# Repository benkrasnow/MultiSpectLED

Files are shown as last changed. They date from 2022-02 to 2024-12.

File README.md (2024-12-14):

# MultiSpectLED
Array of 15 1W LEDs spanning 280nm to 940nm


Notes:  The 280nm LED has a forward voltage drop of between 5V and 7.5V depending on the voltage bin.  This is higher that I expected when I designed the circuit, and it will not work if the power supply is really 5.0V.  It should have a boost converter instead of a buck converter.  However, I happened to receive an LED with a 5.1V drop, and my 5V wall adapter supplies 5.35V at 500mA, so the system works with the buck converter, just barely.  This part of the circuit should be redesigned if 280nm is needed.

UPDATE:  I added 0402 resistors near each buck controller.
The "enable" pin on the PAM2804 buck controller is very high-impedance, and will float around while the MCU is being programmed.  This causes bright flashes, and potentially can draw too much current from the supply, so pull-down resistors *MUST* be added between each PWM control line and ground.  I haven't updated the PCB yet, and fixed it in the prototype by adding resistors:

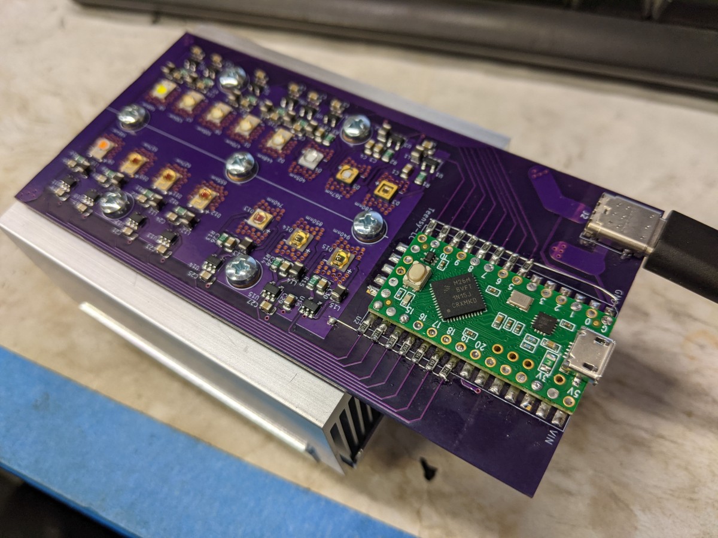
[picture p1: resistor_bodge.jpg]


The heatsink has a 45mm wide rasied section, and the PCB is designed so that all exposed copper is ground within this 45mm strip. I used the PCB itself as a drill guide to drill 2.5mm holes, and then tapped them M3.  I used M3x4 screws to hold the PCB to the heatsink.

Originally, I planned to use Luxeon IR LEDs from Lumileds for the 850 and 940nm.  The thermal pad on these is tied to the anode, so it will not work with the current PCB design. I replaced them with alternate parts with very similar footprint, and have updated the BOM and layout.  

Heatsink and fan: https://www.amazon.com/dp/B00006B8EX
The fan runs nice and quiet on 5V, and provides more than enough airflow

USB-C 5V 4A power adapter:  Digikey 1597-106060004-ND  This should have enough current capacity to run up to 8 LEDs at full power.

Each LED channel is configured for 500mA , which is set by the 0.2 ohm resistor and internal 0.1V reference of the buck controller IC, PAM2804.
Dimming is achieved with PWM, and I used "software PWM" to get 15 separate channels from the Teensy-LC.  The SoftPWM library defaults to 60Hz update, which I noticed flickering, so I edited SoftPWM.cpp to use 120Hz instead.  MCUs with 15+ hardware PWM channels exist, but are more expensive, and not easy to find these days!

The Teensy-LC also provides easy programability for external triggering, remote control via USB serial, etc

The +5V power connection on the Teensy-LC between its USB micro plug and Vin pin should be cut.  There is a thin link between two exposed pads on the underside for this purpose.  This allows the Teensy to be powered only by the Vin pin, which is connected to the USB-C power rail in this design (it must be powered for programming).  If the link is not cut, and both USB connections are made with mismatched voltages (eg 4.9V vs 5.3V), bad currents may flow.

Total cost is about $180, and the 280nm LED alone is $24

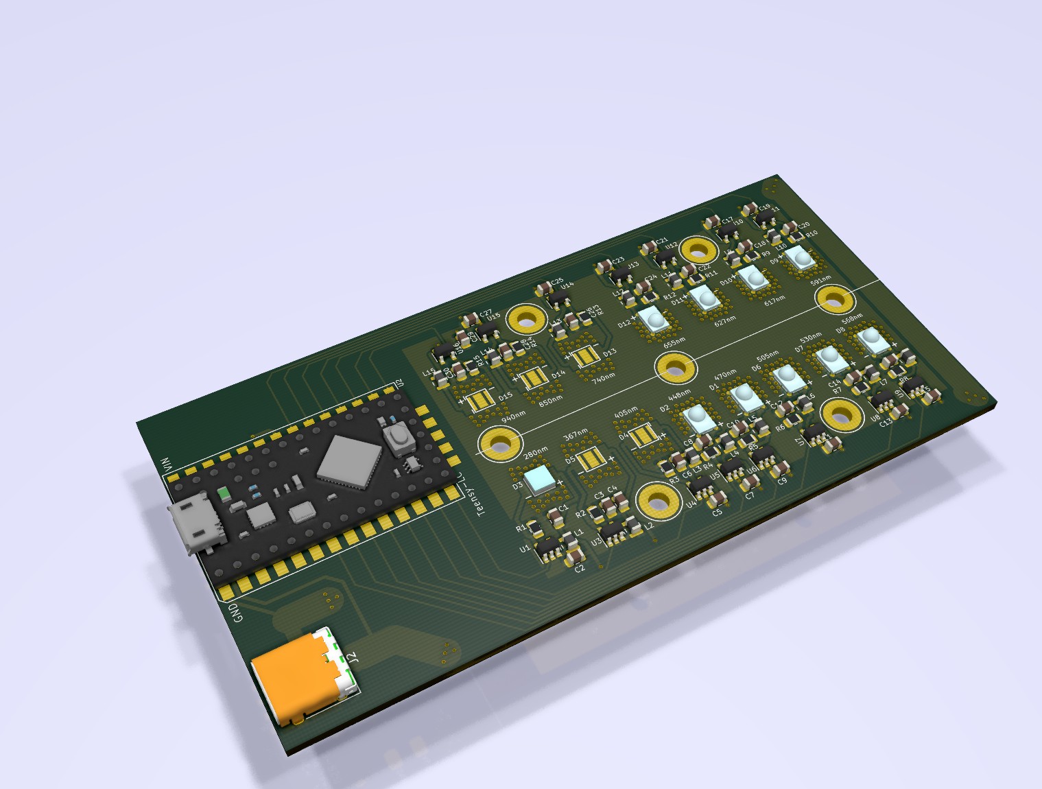
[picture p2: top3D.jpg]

.

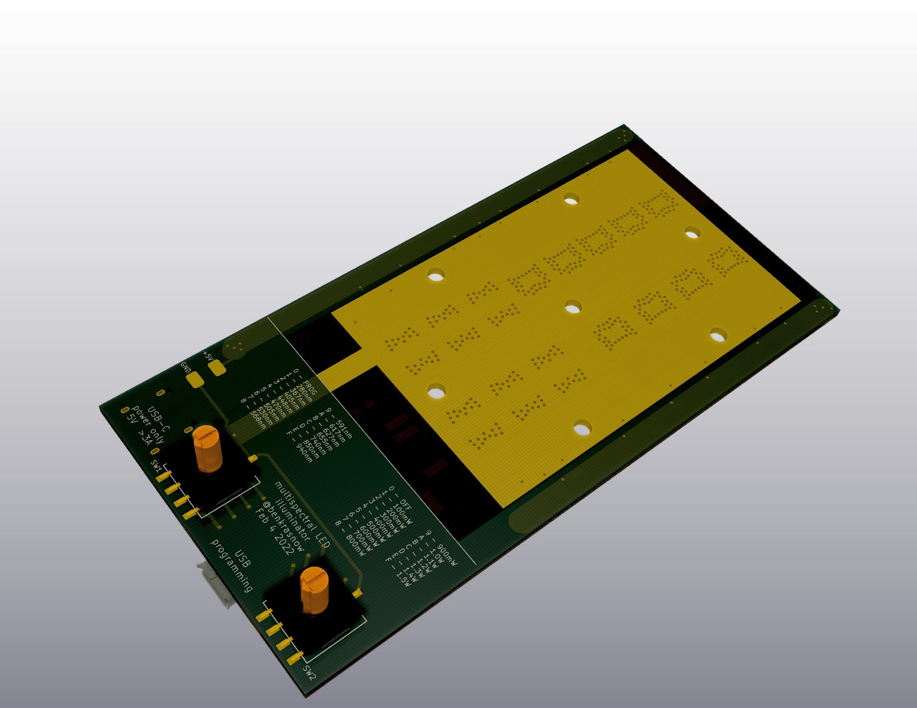
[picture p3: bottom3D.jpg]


Thermal performance looks very good.  At 16C ambient, the hottest part is the inductor at 23C.
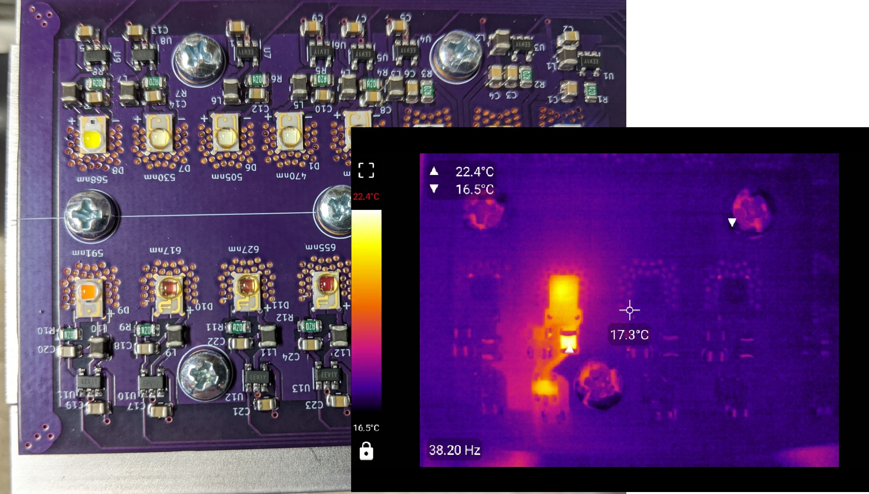
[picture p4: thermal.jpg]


Device was used to create Silver nanoprisms grown into structural colors by high power LEDs

A video can be found here - https://www.youtube.com/watch?v=v8pko9IlFW4

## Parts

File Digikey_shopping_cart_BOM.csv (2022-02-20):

Index | Quantity | Part Number | Manufacturer Part Number | Description | Customer Reference | Available | Backorder | Unit Price | Extended Price USD
1 | 1 | 1416-1038-1-ND | LXML-PR01-0500 | LED LUXEON REBEL BLUE 448NM SMD |  | 1 | 0 | 3.19000 | 3.19
2 | 1 | 1416-1029-1-ND | LXML-PB01-0040 | LED LUXEON REBEL BLUE 470NM SMD |  | 1 | 0 | 4.20000 | 4.20
3 | 1 | 1416-1031-1-ND | LXML-PE01-0070 | LED LUXEON REBEL CYAN 505NM SMD |  | 1 | 0 | 4.47000 | 4.47
4 | 1 | 1416-1036-1-ND | LXML-PM01-0100 | LED LUXEON REBEL GREEN 530NM SMD |  | 1 | 0 | 4.49000 | 4.49
5 | 1 | 1416-1185-1-ND | LXML-PX02-0000 | LED LUXEON REBEL LIME 568NM SMD |  | 1 | 0 | 5.04000 | 5.04
6 | 1 | 1416-1027-1-ND | LXM2-PL01-0000 | LED LUXEON REBEL AMBER 591NM SMD |  | 1 | 0 | 4.49000 | 4.49
7 | 1 | 1416-1026-1-ND | LXM2-PH01-0070 | LED LUXEON REBEL ORG 617NM SMD |  | 1 | 0 | 3.52000 | 3.52
8 | 1 | 1416-1024-1-ND | LXM2-PD01-0050 | LED LUXEON REBEL RED 627NM SMD |  | 1 | 0 | 3.36000 | 3.36
9 | 1 | 1416-1701-1-ND | LXM3-PD01 | LED LUXEON REBEL RED 655NM SMD |  | 1 | 0 | 3.07000 | 3.07
10 | 1 | 1214-XBT-3535-UV-A130-CD270-00CT-ND | XBT-3535-UV-A130-CD270-00 | EMITTER UV 270NM MODULE |  | 1 | 0 | 23.77000 | 23.77
11 | 1 | 2112-CUN6GF1ACT-ND | CUN6GF1A | 367NM CA3535_FLAT PACKAGE |  | 1 | 0 | 9.40000 | 9.40
12 | 1 | 1080-1620-1-ND | ELUA3535OGB-P0010U23240500-VD1M | EMITTER UV 405NM 1000MA SMD |  | 1 | 0 | 3.43000 | 3.43
13 | 1 | 1516-1213-1-ND | QBHP684-IR4BU | LED IR 740NM 700MA SMD |  | 1 | 0 | 5.51000 | 5.51
14 | 25 | PAM2804AAB010DICT-ND | PAM2804AAB010 | IC LED DRIVER RGLTR 1A TSOT25 |  | 25 | 0 | 0.55440 | 13.86
15 | 25 | 587-1621-1-ND | CBC2518T4R7M | FIXED IND 4.7UH 920MA 260MOHM SM |  | 25 | 0 | 0.17600 | 4.40
16 | 50 | 490-3886-1-ND | GRM21BR61C106KE15L | CAP CER 10UF 16V X5R 0805 |  | 50 | 0 | 0.07420 | 3.71
17 | 25 | RL12S.20FCT-ND | RL1220S-R20-F | RES 0.2 OHM 1% 1/3W 0805 |  | 25 | 0 | 0.17640 | 4.41
18 | 1 | 237-1419-ND | WSU050-4000 | AC/DC WALL MOUNT ADAPTER 5V 20W |  | 1 | 0 | 16.01000 | 16.01
19 | 1 | 1568-1233-ND | DEV-13305 | TEENSY-LC KL2X EVAL BRD |  | 1 | 0 | 14.38000 | 14.38
20 | 2 | 360-2543-1-ND | FR02KR16P-R | SWITCH ROTARY DIP HEX 100MA 5V |  | 2 | 0 | 3.76000 | 7.52
21 | 1 | 1516-1173-1-ND | QBHP684U-IRU | EMITTER IR 850NM 700MA SMD |  | 1 | 0 | 4.66000 | 4.66
22 | 1 | 1516-1210-1-ND | QBHP684-IR1BU | LED IR 940NM 700MA SMD |  | 1 | 0 | 4.47000 | 4.47

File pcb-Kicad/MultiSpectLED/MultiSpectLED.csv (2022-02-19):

Source: | C:\Users\Ben\Desktop\MultiSpectLED\MultiSpectLED.sch
Date: | 02/19/22 12:57:11
Tool: | Eeschema (5.1.4)-1
Generator: | C:\Program Files\KiCad\bin\scripting\plugins/bom_csv_grouped_by_value.py
Component Count: | 102
Individual Components:
Item | Qty | Reference(s) | Value | LibPart | Footprint | Datasheet | Digikey Part Number
 |  | C1 | C | MultiSpectLED:C | MultiSpectLED:C_0805_2012Metric | ~ | 490-3886-1-ND
 |  | C2 | C | MultiSpectLED:C | MultiSpectLED:C_0805_2012Metric | ~ | 490-3886-1-ND
 |  | C3 | C | MultiSpectLED:C | MultiSpectLED:C_0805_2012Metric | ~ | 490-3886-1-ND
 |  | C4 | C | MultiSpectLED:C | MultiSpectLED:C_0805_2012Metric | ~ | 490-3886-1-ND
 |  | C5 | C | MultiSpectLED:C | MultiSpectLED:C_0805_2012Metric | ~ | 490-3886-1-ND
 |  | C6 | C | MultiSpectLED:C | MultiSpectLED:C_0805_2012Metric | ~ | 490-3886-1-ND
 |  | C7 | C | MultiSpectLED:C | MultiSpectLED:C_0805_2012Metric | ~ | 490-3886-1-ND
 |  | C8 | C | MultiSpectLED:C | MultiSpectLED:C_0805_2012Metric | ~ | 490-3886-1-ND
 |  | C9 | C | MultiSpectLED:C | MultiSpectLED:C_0805_2012Metric | ~ | 490-3886-1-ND
 |  | C10 | C | MultiSpectLED:C | MultiSpectLED:C_0805_2012Metric | ~ | 490-3886-1-ND
 |  | C11 | C | MultiSpectLED:C | MultiSpectLED:C_0805_2012Metric | ~ | 490-3886-1-ND
 |  | C12 | C | MultiSpectLED:C | MultiSpectLED:C_0805_2012Metric | ~ | 490-3886-1-ND
 |  | C13 | C | MultiSpectLED:C | MultiSpectLED:C_0805_2012Metric | ~ | 490-3886-1-ND
 |  | C14 | C | MultiSpectLED:C | MultiSpectLED:C_0805_2012Metric | ~ | 490-3886-1-ND
 |  | C15 | C | MultiSpectLED:C | MultiSpectLED:C_0805_2012Metric | ~ | 490-3886-1-ND
 |  | C16 | C | MultiSpectLED:C | MultiSpectLED:C_0805_2012Metric | ~ | 490-3886-1-ND
 |  | C17 | C | MultiSpectLED:C | MultiSpectLED:C_0805_2012Metric | ~ | 490-3886-1-ND
 |  | C18 | C | MultiSpectLED:C | MultiSpectLED:C_0805_2012Metric | ~ | 490-3886-1-ND
 |  | C19 | C | MultiSpectLED:C | MultiSpectLED:C_0805_2012Metric | ~ | 490-3886-1-ND
 |  | C20 | C | MultiSpectLED:C | MultiSpectLED:C_0805_2012Metric | ~ | 490-3886-1-ND
 |  | C21 | C | MultiSpectLED:C | MultiSpectLED:C_0805_2012Metric | ~ | 490-3886-1-ND
 |  | C22 | C | MultiSpectLED:C | MultiSpectLED:C_0805_2012Metric | ~ | 490-3886-1-ND
 |  | C23 | C | MultiSpectLED:C | MultiSpectLED:C_0805_2012Metric | ~ | 490-3886-1-ND
 |  | C24 | C | MultiSpectLED:C | MultiSpectLED:C_0805_2012Metric | ~ | 490-3886-1-ND
 |  | C25 | C | MultiSpectLED:C | MultiSpectLED:C_0805_2012Metric | ~ | 490-3886-1-ND
 |  | C26 | C | MultiSpectLED:C | MultiSpectLED:C_0805_2012Metric | ~ | 490-3886-1-ND
 |  | C27 | C | MultiSpectLED:C | MultiSpectLED:C_0805_2012Metric | ~ | 490-3886-1-ND
 |  | C28 | C | MultiSpectLED:C | MultiSpectLED:C_0805_2012Metric | ~ | 490-3886-1-ND
 |  | C29 | C | MultiSpectLED:C | MultiSpectLED:C_0805_2012Metric | ~ | 490-3886-1-ND
 |  | C30 | C | MultiSpectLED:C | MultiSpectLED:C_0805_2012Metric | ~ | 490-3886-1-ND
 |  | D1 | 470nm | MultiSpectLED:LED_PAD | MultiSpectLED:LuxeonRebelColor | ~ | 1416-1029-1-ND
 |  | D2 | 448nm | MultiSpectLED:LED_PAD | MultiSpectLED:LuxeonRebelColor | ~ | 1416-1038-1-ND
 |  | D3 | 280nm | MultiSpectLED:LED_PAD | MultiSpectLED:Luminus_XBT3535 | ~ | 1214-XBT-3535-UV-A130-CD270-00CT-ND
 |  | D4 | 405nm | MultiSpectLED:LED_PAD_ANODE_MARKED | MultiSpectLED:Everlight_ELUA3535 | ~ | 1080-1620-1-ND
 |  | D5 | 367nm | MultiSpectLED:LED_PAD | MultiSpectLED:SeoulViosys_CUN6GF1A | ~ | 2112-CUN6GF1ACT-ND
 |  | D6 | 505nm | MultiSpectLED:LED_PAD | MultiSpectLED:LuxeonRebelColor | ~ | 1416-1031-1-ND
 |  | D7 | 530nm | MultiSpectLED:LED_PAD | MultiSpectLED:LuxeonRebelColor | ~ | 1416-1036-1-ND
 |  | D8 | 568nm | MultiSpectLED:LED_PAD | MultiSpectLED:LuxeonRebelColor | ~ | 1416-1185-1-ND
 |  | D9 | 591nm | MultiSpectLED:LED_PAD | MultiSpectLED:LuxeonRebelColor | ~ | 1416-1027-1-ND
 |  | D10 | 617nm | MultiSpectLED:LED_PAD | MultiSpectLED:LuxeonRebelColor | ~ | 1416-1026-1-ND
 |  | D11 | 627nm | MultiSpectLED:LED_PAD | MultiSpectLED:LuxeonRebelColor | ~ | 1416-1024-1-ND
 |  | D12 | 655nm | MultiSpectLED:LED_PAD | MultiSpectLED:LuxeonRebelColor | ~ | 1416-1701-1-ND
 |  | D13 | 740nm | MultiSpectLED:LED_PAD_ANODE_MARKED | MultiSpectLED:QT_Brightek_QBHP684 | ~ | 1516-1213-1-ND
 |  | D14 | 850nm | MultiSpectLED:LED_PAD_ANODE_MARKED | MultiSpectLED:QT_Brightek_QBHP684 | ~
 |  | D15 | 940nm | MultiSpectLED:LED_PAD_ANODE_MARKED | MultiSpectLED:QT_Brightek_QBHP684 | ~
 |  | H1 | 3mm_PTH | MultiSpectLED:3mm_PTH | MultiSpectLED:3mm_PTH
 |  | H2 | 3mm_PTH | MultiSpectLED:3mm_PTH | MultiSpectLED:3mm_PTH
 |  | H3 | 3mm_PTH | MultiSpectLED:3mm_PTH | MultiSpectLED:3mm_PTH
 |  | H4 | 3mm_PTH | MultiSpectLED:3mm_PTH | MultiSpectLED:3mm_PTH
 |  | H5 | 3mm_PTH | MultiSpectLED:3mm_PTH | MultiSpectLED:3mm_PTH
 |  | H6 | 3mm_PTH | MultiSpectLED:3mm_PTH | MultiSpectLED:3mm_PTH
 |  | H7 | 3mm_PTH | MultiSpectLED:3mm_PTH | MultiSpectLED:3mm_PTH
 |  | J1 | Conn_01x02_Female | Connector:Conn_01x02_Female | MultiSpectLED:FAN_PADS | ~
 |  | J2 | USB_C_Receptacle_USB2.0 | Connector:USB_C_Receptacle_USB2.0 | MultiSpectLED:USB_C_Receptacle_Amphenol_12401610E4-2A | https://www.usb.org/sites/default/files/documents/usb_type-c.zip | CP-036AHPJCT-ND
 |  | L1 | 4.7u | MultiSpectLED:L | MultiSpectLED:L_1007_2518Metric | ~ | 587-1621-1-ND
 |  | L2 | 4.7u | MultiSpectLED:L | MultiSpectLED:L_1007_2518Metric | ~ | 587-1621-1-ND
 |  | L3 | 4.7u | MultiSpectLED:L | MultiSpectLED:L_1007_2518Metric | ~ | 587-1621-1-ND
 |  | L4 | 4.7u | MultiSpectLED:L | MultiSpectLED:L_1007_2518Metric | ~ | 587-1621-1-ND
 |  | L5 | 4.7u | MultiSpectLED:L | MultiSpectLED:L_1007_2518Metric | ~ | 587-1621-1-ND
 |  | L6 | 4.7u | MultiSpectLED:L | MultiSpectLED:L_1007_2518Metric | ~ | 587-1621-1-ND
 |  | L7 | 4.7u | MultiSpectLED:L | MultiSpectLED:L_1007_2518Metric | ~ | 587-1621-1-ND
 |  | L8 | 4.7u | MultiSpectLED:L | MultiSpectLED:L_1007_2518Metric | ~ | 587-1621-1-ND
 |  | L9 | 4.7u | MultiSpectLED:L | MultiSpectLED:L_1007_2518Metric | ~ | 587-1621-1-ND
 |  | L10 | 4.7u | MultiSpectLED:L | MultiSpectLED:L_1007_2518Metric | ~ | 587-1621-1-ND
 |  | L11 | 4.7u | MultiSpectLED:L | MultiSpectLED:L_1007_2518Metric | ~ | 587-1621-1-ND
 |  | L12 | 4.7u | MultiSpectLED:L | MultiSpectLED:L_1007_2518Metric | ~ | 587-1621-1-ND
 |  | L13 | 4.7u | MultiSpectLED:L | MultiSpectLED:L_1007_2518Metric | ~ | 587-1621-1-ND
 |  | L14 | 4.7u | MultiSpectLED:L | MultiSpectLED:L_1007_2518Metric | ~ | 587-1621-1-ND
 |  | L15 | 4.7u | MultiSpectLED:L | MultiSpectLED:L_1007_2518Metric | ~ | 587-1621-1-ND
 |  | R1 | 0.2 | MultiSpectLED:R | MultiSpectLED:R_0805_2012Metric | ~ | RL12S.20FCT-ND
 |  | R2 | 0.2 | MultiSpectLED:R | MultiSpectLED:R_0805_2012Metric | ~ | RL12S.20FCT-ND
 |  | R3 | 0.2 | MultiSpectLED:R | MultiSpectLED:R_0805_2012Metric | ~ | RL12S.20FCT-ND
 |  | R4 | 0.2 | MultiSpectLED:R | MultiSpectLED:R_0805_2012Metric | ~ | RL12S.20FCT-ND
 |  | R5 | 0.2 | MultiSpectLED:R | MultiSpectLED:R_0805_2012Metric | ~ | RL12S.20FCT-ND
 |  | R6 | 0.2 | MultiSpectLED:R | MultiSpectLED:R_0805_2012Metric | ~ | RL12S.20FCT-ND
 |  | R7 | 0.2 | MultiSpectLED:R | MultiSpectLED:R_0805_2012Metric | ~ | RL12S.20FCT-ND
 |  | R8 | 0.2 | MultiSpectLED:R | MultiSpectLED:R_0805_2012Metric | ~ | RL12S.20FCT-ND
 |  | R9 | 0.2 | MultiSpectLED:R | MultiSpectLED:R_0805_2012Metric | ~ | RL12S.20FCT-ND
 |  | R10 | 0.2 | MultiSpectLED:R | MultiSpectLED:R_0805_2012Metric | ~ | RL12S.20FCT-ND
 |  | R11 | 0.2 | MultiSpectLED:R | MultiSpectLED:R_0805_2012Metric | ~ | RL12S.20FCT-ND
 |  | R12 | 0.2 | MultiSpectLED:R | MultiSpectLED:R_0805_2012Metric | ~ | RL12S.20FCT-ND
 |  | R13 | 0.2 | MultiSpectLED:R | MultiSpectLED:R_0805_2012Metric | ~ | RL12S.20FCT-ND
 |  | R14 | 0.2 | MultiSpectLED:R | MultiSpectLED:R_0805_2012Metric | ~ | RL12S.20FCT-ND
 |  | R15 | 0.2 | MultiSpectLED:R | MultiSpectLED:R_0805_2012Metric | ~ | RL12S.20FCT-ND
 |  | SW1 | NKK_HEXADEC | MultiSpectLED:NKK_HEXADEC | MultiSpectLED:NKK_FR02 |  | 360-2543-1-ND
 |  | SW2 | NKK_HEXADEC | MultiSpectLED:NKK_HEXADEC | MultiSpectLED:NKK_FR02 |  | 360-2543-1-ND
 |  | U1 | PAM2804 | MultiSpectLED:PAM2804 | MultiSpectLED:SOT-23-5 |  | PAM2804AAB010DICT-ND
 |  | U2 | TeensyLC | MultiSpectLED:TeensyLC | MultiSpectLED:TeensyLC |  | 1568-1233-ND
 |  | U3 | PAM2804 | MultiSpectLED:PAM2804 | MultiSpectLED:SOT-23-5 |  | PAM2804AAB010DICT-ND
 |  | U4 | PAM2804 | MultiSpectLED:PAM2804 | MultiSpectLED:SOT-23-5 |  | PAM2804AAB010DICT-ND
 |  | U5 | PAM2804 | MultiSpectLED:PAM2804 | MultiSpectLED:SOT-23-5 |  | PAM2804AAB010DICT-ND
 |  | U6 | PAM2804 | MultiSpectLED:PAM2804 | MultiSpectLED:SOT-23-5 |  | PAM2804AAB010DICT-ND
 |  | U7 | PAM2804 | MultiSpectLED:PAM2804 | MultiSpectLED:SOT-23-5 |  | PAM2804AAB010DICT-ND
 |  | U8 | PAM2804 | MultiSpectLED:PAM2804 | MultiSpectLED:SOT-23-5 |  | PAM2804AAB010DICT-ND
 |  | U9 | PAM2804 | MultiSpectLED:PAM2804 | MultiSpectLED:SOT-23-5 |  | PAM2804AAB010DICT-ND
 |  | U10 | PAM2804 | MultiSpectLED:PAM2804 | MultiSpectLED:SOT-23-5 |  | PAM2804AAB010DICT-ND
 |  | U11 | PAM2804 | MultiSpectLED:PAM2804 | MultiSpectLED:SOT-23-5 |  | PAM2804AAB010DICT-ND
 |  | U12 | PAM2804 | MultiSpectLED:PAM2804 | MultiSpectLED:SOT-23-5 |  | PAM2804AAB010DICT-ND
 |  | U13 | PAM2804 | MultiSpectLED:PAM2804 | MultiSpectLED:SOT-23-5 |  | PAM2804AAB010DICT-ND
 |  | U14 | PAM2804 | MultiSpectLED:PAM2804 | MultiSpectLED:SOT-23-5 |  | PAM2804AAB010DICT-ND
 |  | U15 | PAM2804 | MultiSpectLED:PAM2804 | MultiSpectLED:SOT-23-5 |  | PAM2804AAB010DICT-ND
 |  | U16 | PAM2804 | MultiSpectLED:PAM2804 | MultiSpectLED:SOT-23-5 |  | PAM2804AAB010DICT-ND
Collated Components:
Item | Qty | Reference(s) | Value | LibPart | Footprint | Datasheet | Digikey Part Number
1 | 30 | C1, C2, C3, C4, C5, C6, C7, C8, C9, C10, C11, C12, C13, C14, C15, C16, C17, C18, C19, C20, C21, C22, C23, C24, C25, C26, C27, C28, C29, C30 | C | MultiSpectLED:C | MultiSpectLED:C_0805_2012Metric | ~ | 490-3886-1-ND
2 | 1 | D1 | 470nm | MultiSpectLED:LED_PAD | MultiSpectLED:LuxeonRebelColor | ~ | 1416-1029-1-ND
3 | 1 | D2 | 448nm | MultiSpectLED:LED_PAD | MultiSpectLED:LuxeonRebelColor | ~ | 1416-1038-1-ND
4 | 1 | D3 | 280nm | MultiSpectLED:LED_PAD | MultiSpectLED:Luminus_XBT3535 | ~ | 1214-XBT-3535-UV-A130-CD270-00CT-ND
5 | 1 | D4 | 405nm | MultiSpectLED:LED_PAD_ANODE_MARKED | MultiSpectLED:Everlight_ELUA3535 | ~ | 1080-1620-1-ND
6 | 1 | D5 | 367nm | MultiSpectLED:LED_PAD | MultiSpectLED:SeoulViosys_CUN6GF1A | ~ | 2112-CUN6GF1ACT-ND
7 | 1 | D6 | 505nm | MultiSpectLED:LED_PAD | MultiSpectLED:LuxeonRebelColor | ~ | 1416-1031-1-ND
8 | 1 | D7 | 530nm | MultiSpectLED:LED_PAD | MultiSpectLED:LuxeonRebelColor | ~ | 1416-1036-1-ND
9 | 1 | D8 | 568nm | MultiSpectLED:LED_PAD | MultiSpectLED:LuxeonRebelColor | ~ | 1416-1185-1-ND
10 | 1 | D9 | 591nm | MultiSpectLED:LED_PAD | MultiSpectLED:LuxeonRebelColor | ~ | 1416-1027-1-ND
11 | 1 | D10 | 617nm | MultiSpectLED:LED_PAD | MultiSpectLED:LuxeonRebelColor | ~ | 1416-1026-1-ND
12 | 1 | D11 | 627nm | MultiSpectLED:LED_PAD | MultiSpectLED:LuxeonRebelColor | ~ | 1416-1024-1-ND
13 | 1 | D12 | 655nm | MultiSpectLED:LED_PAD | MultiSpectLED:LuxeonRebelColor | ~ | 1416-1701-1-ND
14 | 1 | D13 | 740nm | MultiSpectLED:LED_PAD_ANODE_MARKED | MultiSpectLED:QT_Brightek_QBHP684 | ~ | 1516-1213-1-ND
15 | 1 | D14 | 850nm | MultiSpectLED:LED_PAD_ANODE_MARKED | MultiSpectLED:QT_Brightek_QBHP684 | ~
16 | 1 | D15 | 940nm | MultiSpectLED:LED_PAD_ANODE_MARKED | MultiSpectLED:QT_Brightek_QBHP684 | ~
17 | 7 | H1, H2, H3, H4, H5, H6, H7 | 3mm_PTH | MultiSpectLED:3mm_PTH | MultiSpectLED:3mm_PTH
18 | 1 | J1 | Conn_01x02_Female | Connector:Conn_01x02_Female | MultiSpectLED:FAN_PADS | ~
19 | 1 | J2 | USB_C_Receptacle_USB2.0 | Connector:USB_C_Receptacle_USB2.0 | MultiSpectLED:USB_C_Receptacle_Amphenol_12401610E4-2A | https://www.usb.org/sites/default/files/documents/usb_type-c.zip | CP-036AHPJCT-ND
20 | 15 | L1, L2, L3, L4, L5, L6, L7, L8, L9, L10, L11, L12, L13, L14, L15 | 4.7u | MultiSpectLED:L | MultiSpectLED:L_1007_2518Metric | ~ | 587-1621-1-ND
21 | 15 | R1, R2, R3, R4, R5, R6, R7, R8, R9, R10, R11, R12, R13, R14, R15 | 0.2 | MultiSpectLED:R | MultiSpectLED:R_0805_2012Metric | ~ | RL12S.20FCT-ND
22 | 2 | SW1, SW2 | NKK_HEXADEC | MultiSpectLED:NKK_HEXADEC | MultiSpectLED:NKK_FR02 |  | 360-2543-1-ND
23 | 15 | U1, U3, U4, U5, U6, U7, U8, U9, U10, U11, U12, U13, U14, U15, U16 | PAM2804 | MultiSpectLED:PAM2804 | MultiSpectLED:SOT-23-5 |  | PAM2804AAB010DICT-ND
24 | 1 | U2 | TeensyLC | MultiSpectLED:TeensyLC | MultiSpectLED:TeensyLC |  | 1568-1233-ND

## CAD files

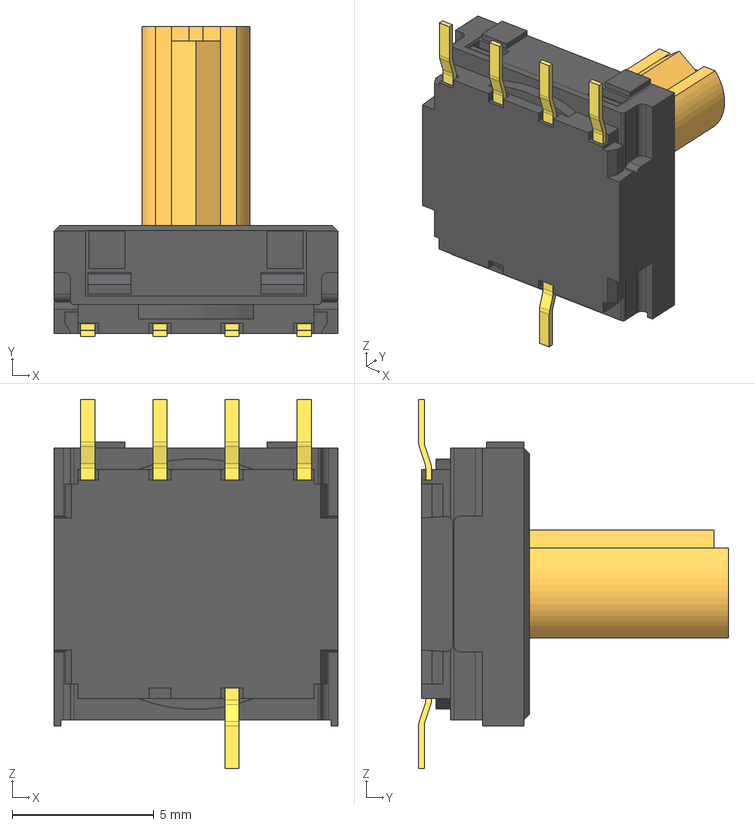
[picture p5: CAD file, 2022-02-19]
pcb-Kicad/MultiSpectLED/FR02KR16P.stp
10.0 x 10.9 x 13.0 mm
_FR02FR16Pbody
_FR02FRPtrmnls
_FR02KRactu

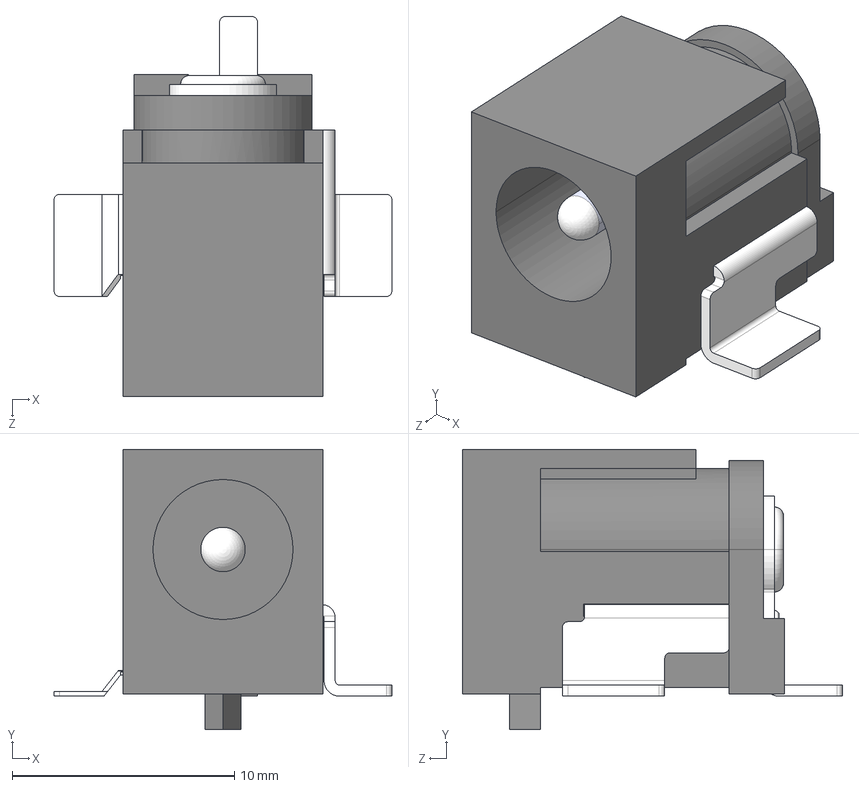
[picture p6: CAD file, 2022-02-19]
pcb-Kicad/MultiSpectLED/CUI_DEVICES_PJ-036AH-SMT-TR.step
15.2 x 12.6 x 17.1 mm

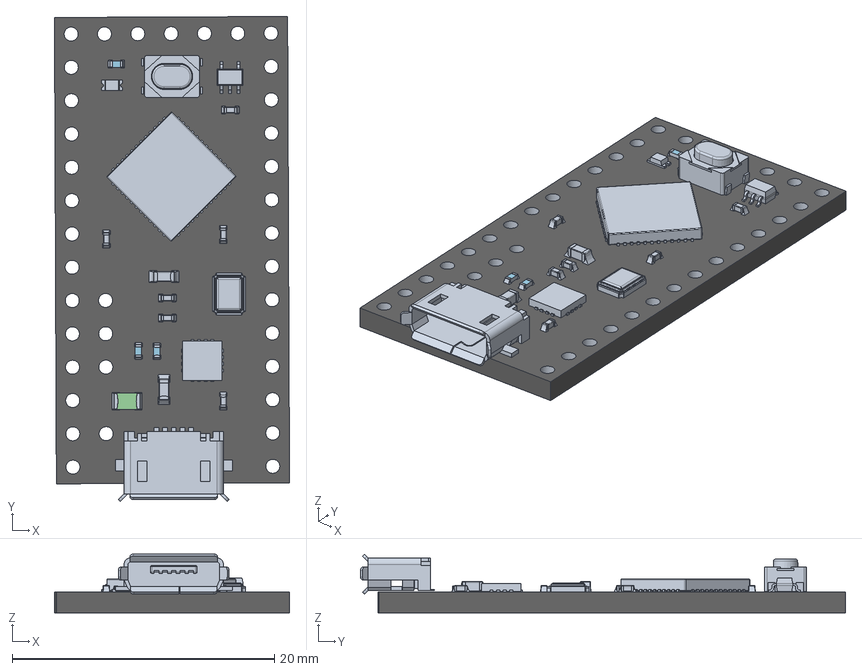
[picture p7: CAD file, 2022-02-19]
pcb-Kicad/MultiSpectLED/Teensy_lc.stp
17.9 x 37.0 x 4.49 mm
board
micro_usb_plastic (1)
micro_usb_shell (1)
lead
diode_0402 v1 x 4
cap0603_03 v3 x 2
qfn48 v2
cap0402 v2 x 6
resistor_0805 v2
smt_led_0603 v2
package
lead (1)

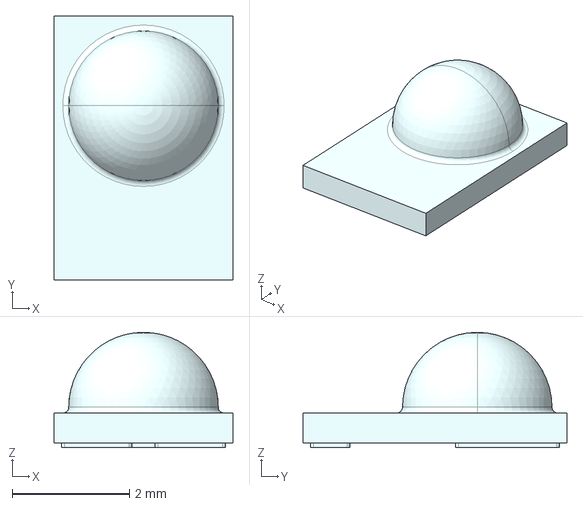
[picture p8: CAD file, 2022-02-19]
pcb-Kicad/MultiSpectLED/LuxeonRebel.stp
3.05 x 4.49 x 1.96 mm

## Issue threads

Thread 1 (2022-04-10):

[FEATURE REQUEST] Add Kitspace one click pricing

darigovresearch, 2022-04-10:
[Kitspace](https://kitspace.org/) is a project that really helps with building open source hardware as it allows you to (when properly implemented) have an almost one click pricing for the PCB and electronics components. If setup by the maintainers it would really decrease uncertainty if the components chosen are the ones that work reliably.

We helped implement it for the [Infidel sensor](https://kitspace.org/boards/github.com/drspangle/infidel-sensor/) and it is relatively straightforward to implement and lets users have self-autonomy to replicate the work, build upon it and put it in the hands of users.

Examples of very good implementations of this are the [Open book](https://kitspace.org/boards/github.com/joeycastillo/the-open-book/open-book/) and [ebook wing](https://kitspace.org/boards/github.com/joeycastillo/the-open-book/ebook-wing/) projects by @joeycastillo

https://kitspace.org/1-click-bom/
https://github.com/kitspace/1clickBOM#readme

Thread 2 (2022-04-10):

[FEATURE REQUEST] Add link to video in readme

darigovresearch, 2022-04-10:
Would be great to have a link to the video in the readme to see the device in use

https://www.youtube.com/watch?v=v8pko9IlFW4

darigovresearch, 2022-04-10:
Pull request https://github.com/benkrasnow/MultiSpectLED/pull/3 would resolve this issue

Closed 2024-12-14.

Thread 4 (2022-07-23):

Suggestion: Add 815nm

tkircher, 2022-07-23:
There's a compatible LED available on Digi-key that is between 740nm and 850nm and is in stock:

https://www.digikey.com/en/products/detail/luminus-devices-inc/SST-10-IRD-B90H-S810/13557593

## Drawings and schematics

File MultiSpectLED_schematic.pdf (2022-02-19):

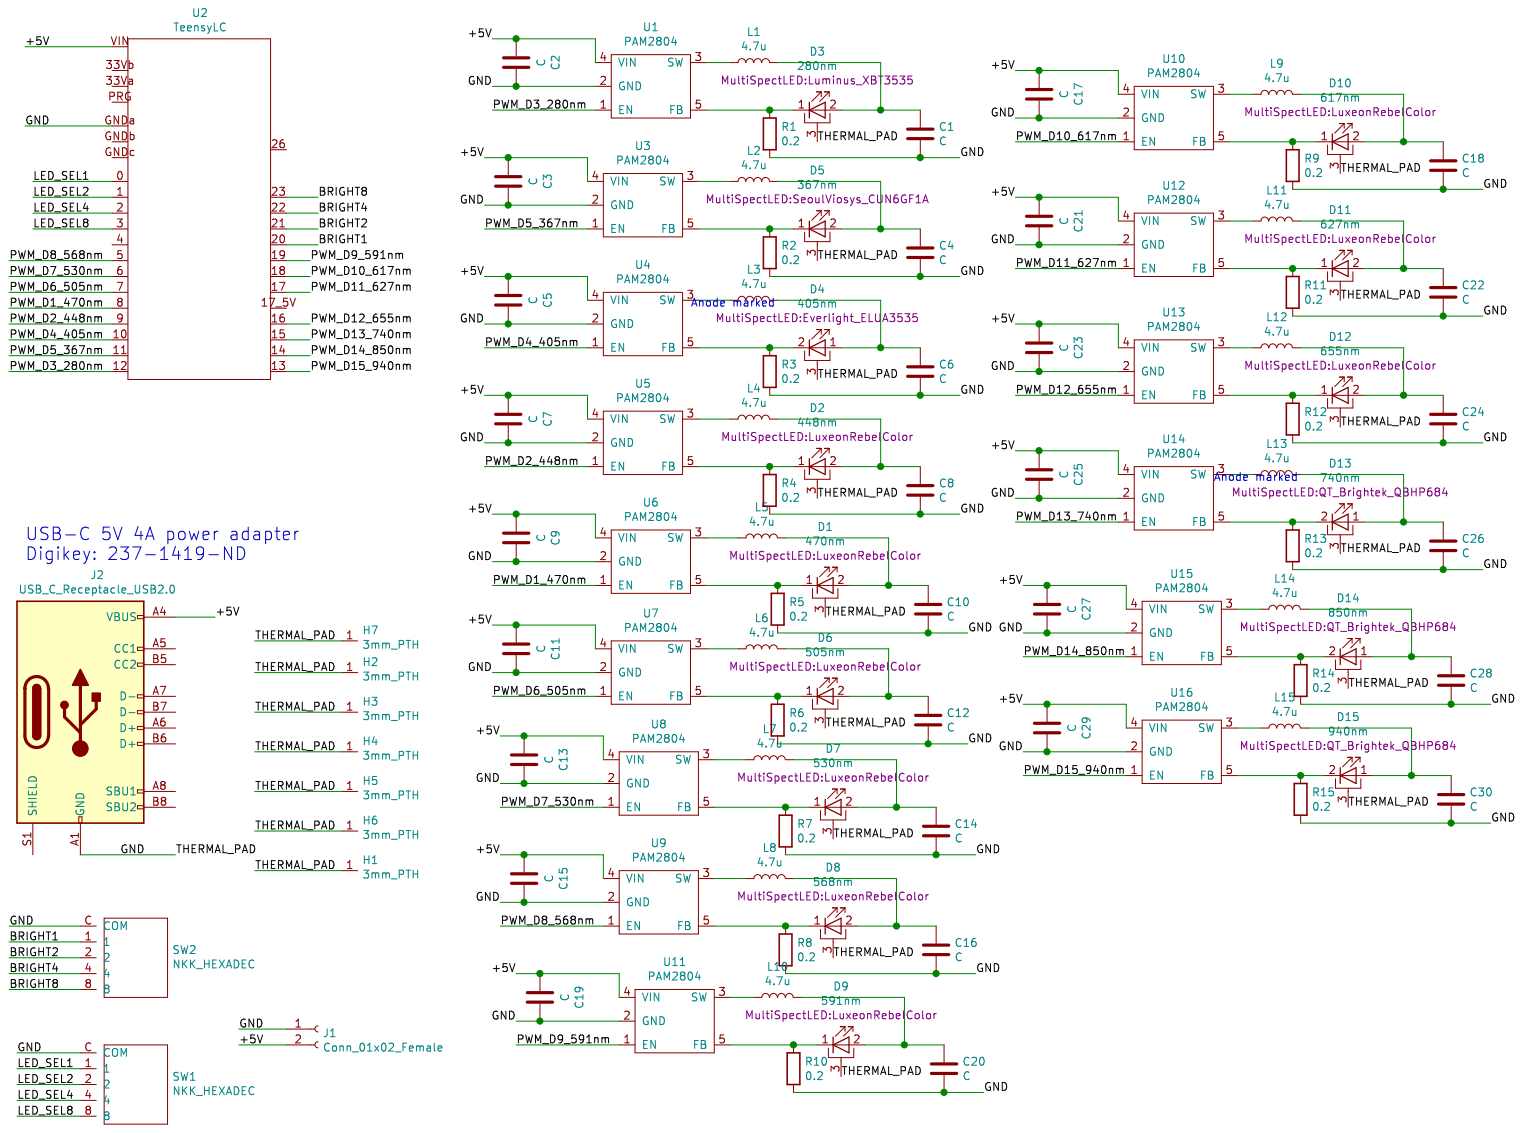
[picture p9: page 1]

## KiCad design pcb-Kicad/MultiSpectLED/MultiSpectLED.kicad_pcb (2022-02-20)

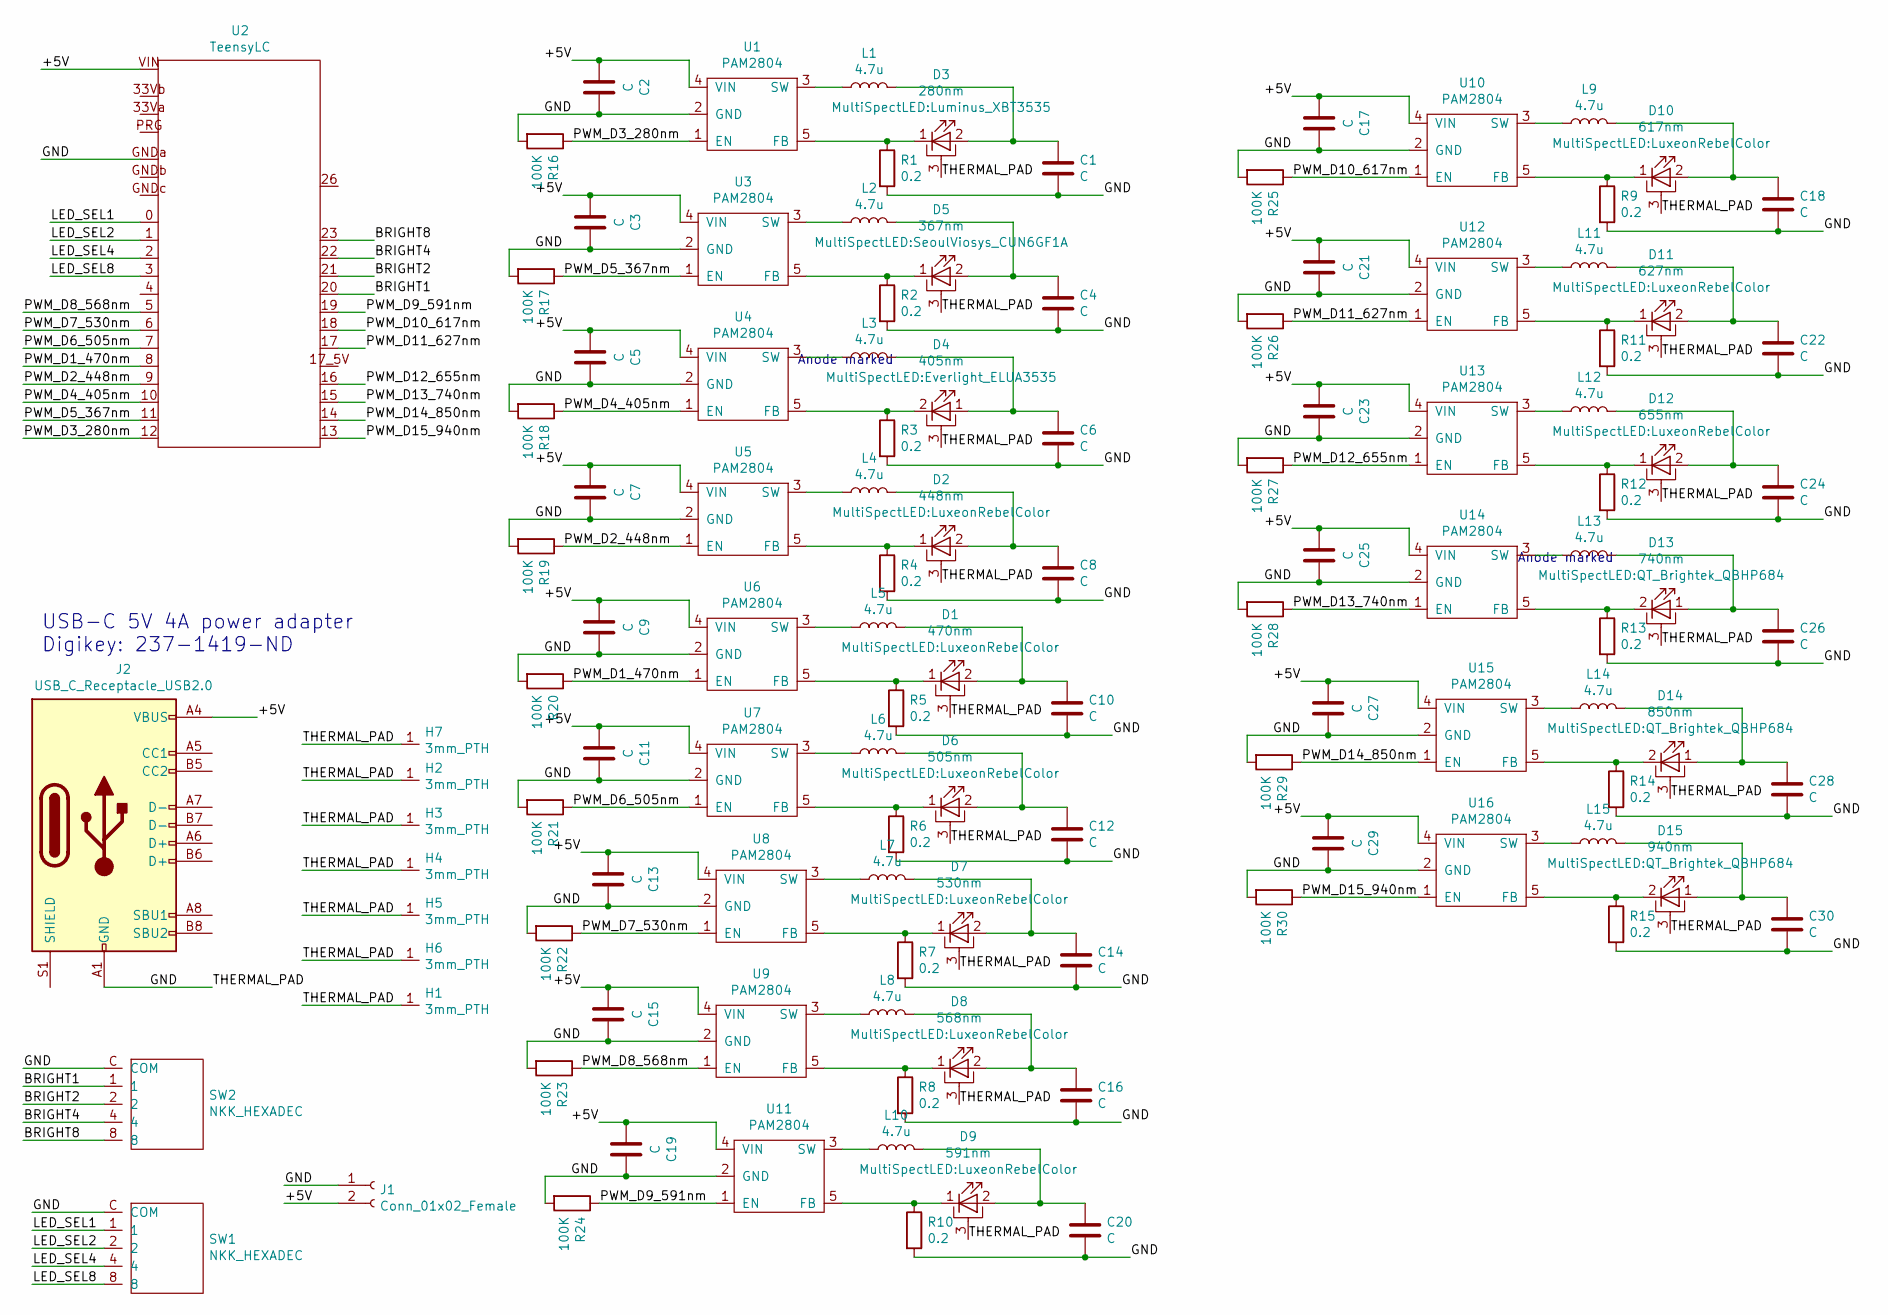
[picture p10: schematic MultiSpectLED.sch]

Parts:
C1, C2, C3, C4, C5, C6, C7, C8, C9, C10, C11, C12, C13, C14, C15, C16, C17, C18, C19, C20, C21, C22, C23, C24, C25, C26, C27, C28, C29, C30: C; C_0805_2012Metric; Digikey Part Number 490-3886-1-ND
D1: 470nm; LuxeonRebelColor; Digikey Part Number 1416-1029-1-ND
D2: 448nm; LuxeonRebelColor; Digikey Part Number 1416-1038-1-ND
D3: 280nm; Luminus_XBT3535; Digikey Part Number 1214-XBT-3535-UV-A130-CD270-00CT-ND
D4: 405nm; Everlight_ELUA3535; Digikey Part Number 1080-1620-1-ND
D5: 367nm; SeoulViosys_CUN6GF1A; Digikey Part Number 2112-CUN6GF1ACT-ND
D6: 505nm; LuxeonRebelColor; Digikey Part Number 1416-1031-1-ND
D7: 530nm; LuxeonRebelColor; Digikey Part Number 1416-1036-1-ND
D8: 568nm; LuxeonRebelColor; Digikey Part Number 1416-1185-1-ND
D9: 591nm; LuxeonRebelColor; Digikey Part Number 1416-1027-1-ND
D10: 617nm; LuxeonRebelColor; Digikey Part Number 1416-1026-1-ND
D11: 627nm; LuxeonRebelColor; Digikey Part Number 1416-1024-1-ND
D12: 655nm; LuxeonRebelColor; Digikey Part Number 1416-1701-1-ND
D13: 740nm; QT_Brightek_QBHP684; Digikey Part Number 1516-1213-1-ND
D14: 850nm; QT_Brightek_QBHP684
D15: 940nm; QT_Brightek_QBHP684
H1, H2, H3, H4, H5, H6, H7: 3mm_PTH
J1: Conn_01x02_Female; FAN_PADS
J2: USB_C_Receptacle_USB2.0; USB_C_Receptacle_Amphenol_12401610E4-2A; Digikey Part Number CP-036AHPJCT-ND
L1, L2, L3, L4, L5, L6, L7, L8, L9, L10, L11, L12, L13, L14, L15: 4.7u; L_1007_2518Metric; Digikey Part Number 587-1621-1-ND
R1, R2, R3, R4, R5, R6, R7, R8, R9, R10, R11, R12, R13, R14, R15: 0.2; R_0805_2012Metric; Digikey Part Number RL12S.20FCT-ND
R16, R17, R18, R19, R20, R21, R22, R23, R24, R25, R26, R27, R28, R29, R30: 100K; R_0402_1005Metric; Digikey Part Number RC1005F104CS
SW1, SW2: NKK_HEXADEC; NKK_FR02; Digikey Part Number 360-2543-1-ND
U1, U3, U4, U5, U6, U7, U8, U9, U10, U11, U12, U13, U14, U15, U16: PAM2804; SOT-23-5; Digikey Part Number PAM2804AAB010DICT-ND
U2: TeensyLC; Digikey Part Number 1568-1233-ND

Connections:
/+5V: C2.2, C3.2, C5.2, C7.2, C9.2, C11.2, C13.2, C15.2, C17.2, C19.2, C21.2, C23.2, C25.2, C27.2, C29.2, J1.2, J2.A4 (VBUS), J2.A9 (VBUS), J2.B4 (VBUS), J2.B9 (VBUS), U1.4 (VIN), U2.VIN, U3.4 (VIN), U4.4 (VIN), U5.4 (VIN), U6.4 (VIN), U7.4 (VIN), U8.4 (VIN), U9.4 (VIN), U10.4 (VIN), U11.4 (VIN), U12.4 (VIN), U13.4 (VIN), U14.4 (VIN), U15.4 (VIN), U16.4 (VIN)
/BRIGHT1: SW2.1, U2.20
/BRIGHT2: SW2.2, U2.21
/BRIGHT4: SW2.4, U2.22
/BRIGHT8: SW2.8, U2.23
/GND: C1.2, C2.1, C3.1, C4.2, C5.1, C6.2, C7.1, C8.2, C9.1, C10.2, C11.1, C12.2, C13.1, C14.2, C15.1, C16.2, C17.1, C18.2, C19.1, C20.2, C21.1, C22.2, C23.1, C24.2, C25.1, C26.2, C27.1, C28.2, C29.1, C30.2, D1.3 (PAD), D2.3 (PAD), D3.3 (PAD), D4.3 (PAD), D5.3 (PAD), D6.3 (PAD), D7.3 (PAD), D8.3 (PAD), D9.3 (PAD), D10.3 (PAD), D11.3 (PAD), D12.3 (PAD), D13.3 (PAD), D14.3 (PAD), D15.3 (PAD), H1.1, H2.1, H3.1, H4.1, H5.1, H6.1, H7.1, J1.1, J2.A1 (GND), J2.A12 (GND), J2.B1 (GND), J2.B12 (GND), R1.2, R2.2, R3.2, R4.2, R5.2, R6.2, R7.2, R8.2, R9.2, R10.2, R11.2, R12.2, R13.2, R14.2, R15.2, R16.2, R17.2, R18.2, R19.2, R20.2, R21.2, R22.2, R23.2, R24.2, R25.2, R26.2, R27.2, R28.2, R29.2, R30.2, SW1.C (COM), SW2.C (COM), U1.2 (GND), U2.GNDa, U3.2 (GND), U4.2 (GND), U5.2 (GND), U6.2 (GND), U7.2 (GND), U8.2 (GND), U9.2 (GND), U10.2 (GND), U11.2 (GND), U12.2 (GND), U13.2 (GND), U14.2 (GND), U15.2 (GND), U16.2 (GND)
/LED_SEL1: SW1.1, U2.0
/LED_SEL2: SW1.2, U2.1
/LED_SEL4: SW1.4, U2.2
/LED_SEL8: SW1.8, U2.3
/PWM_D1_470nm: R20.1, U2.8, U6.1 (EN)
/PWM_D2_448nm: R19.1, U2.9, U5.1 (EN)
/PWM_D3_280nm: R16.1, U1.1 (EN), U2.12
/PWM_D4_405nm: R18.1, U2.10, U4.1 (EN)
/PWM_D5_367nm: R17.1, U2.11, U3.1 (EN)
/PWM_D6_505nm: R21.1, U2.7, U7.1 (EN)
/PWM_D7_530nm: R22.1, U2.6, U8.1 (EN)
/PWM_D8_568nm: R23.1, U2.5, U9.1 (EN)
/PWM_D9_591nm: R24.1, U2.19, U11.1 (EN)
/PWM_D10_617nm: R25.1, U2.18, U10.1 (EN)
/PWM_D11_627nm: R26.1, U2.17, U12.1 (EN)
/PWM_D12_655nm: R27.1, U2.16, U13.1 (EN)
/PWM_D13_740nm: R28.1, U2.15, U14.1 (EN)
/PWM_D14_850nm: R29.1, U2.14, U15.1 (EN)
/PWM_D15_940nm: R30.1, U2.13, U16.1 (EN)
unnamed: C1.1, D3.2 (A), L1.2
unnamed: C4.1, D5.2 (A), L2.2
unnamed: C6.1, D4.1 (A), L3.2
unnamed: C8.1, D2.2 (A), L4.2
unnamed: C10.1, D1.2 (A), L5.2
unnamed: C12.1, D6.2 (A), L6.2
unnamed: C14.1, D7.2 (A), L7.2
unnamed: C16.1, D8.2 (A), L8.2
unnamed: C18.1, D10.2 (A), L9.2
unnamed: C20.1, D9.2 (A), L10.2
unnamed: C22.1, D11.2 (A), L11.2
unnamed: C24.1, D12.2 (A), L12.2
unnamed: C26.1, D13.1 (A), L13.2
unnamed: C28.1, D14.1 (A), L14.2
unnamed: C30.1, D15.1 (A), L15.2
unnamed: D1.1 (K), R5.1, U6.5 (FB)
unnamed: D2.1 (K), R4.1, U5.5 (FB)
unnamed: D3.1 (K), R1.1, U1.5 (FB)
unnamed: D4.2 (K), R3.1, U4.5 (FB)
unnamed: D5.1 (K), R2.1, U3.5 (FB)
unnamed: D6.1 (K), R6.1, U7.5 (FB)
unnamed: D7.1 (K), R7.1, U8.5 (FB)
unnamed: D8.1 (K), R8.1, U9.5 (FB)
unnamed: D9.1 (K), R10.1, U11.5 (FB)
unnamed: D10.1 (K), R9.1, U10.5 (FB)
unnamed: D11.1 (K), R11.1, U12.5 (FB)
unnamed: D12.1 (K), R12.1, U13.5 (FB)
unnamed: D13.2 (K), R13.1, U14.5 (FB)
unnamed: D14.2 (K), R14.1, U15.5 (FB)
unnamed: D15.2 (K), R15.1, U16.5 (FB)
unnamed: L1.1, U1.3 (SW)
unnamed: L2.1, U3.3 (SW)
unnamed: L3.1, U4.3 (SW)
unnamed: L4.1, U5.3 (SW)
unnamed: L5.1, U6.3 (SW)
unnamed: L6.1, U7.3 (SW)
unnamed: L7.1, U8.3 (SW)
unnamed: L8.1, U9.3 (SW)
unnamed: L9.1, U10.3 (SW)
unnamed: L10.1, U11.3 (SW)
unnamed: L11.1, U12.3 (SW)
unnamed: L12.1, U13.3 (SW)
unnamed: L13.1, U14.3 (SW)
unnamed: L14.1, U15.3 (SW)
unnamed: L15.1, U16.3 (SW)

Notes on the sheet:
Anode marked
USB-C 5V 4A power adapter Digikey: 237-1419-ND

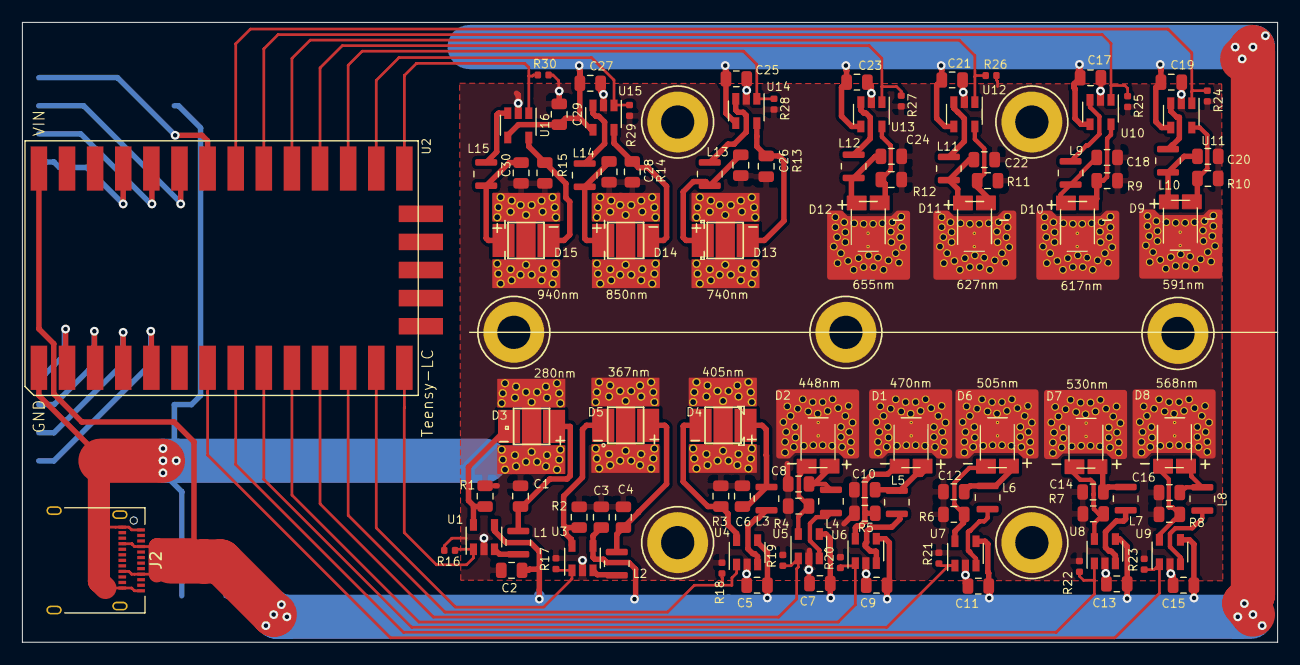
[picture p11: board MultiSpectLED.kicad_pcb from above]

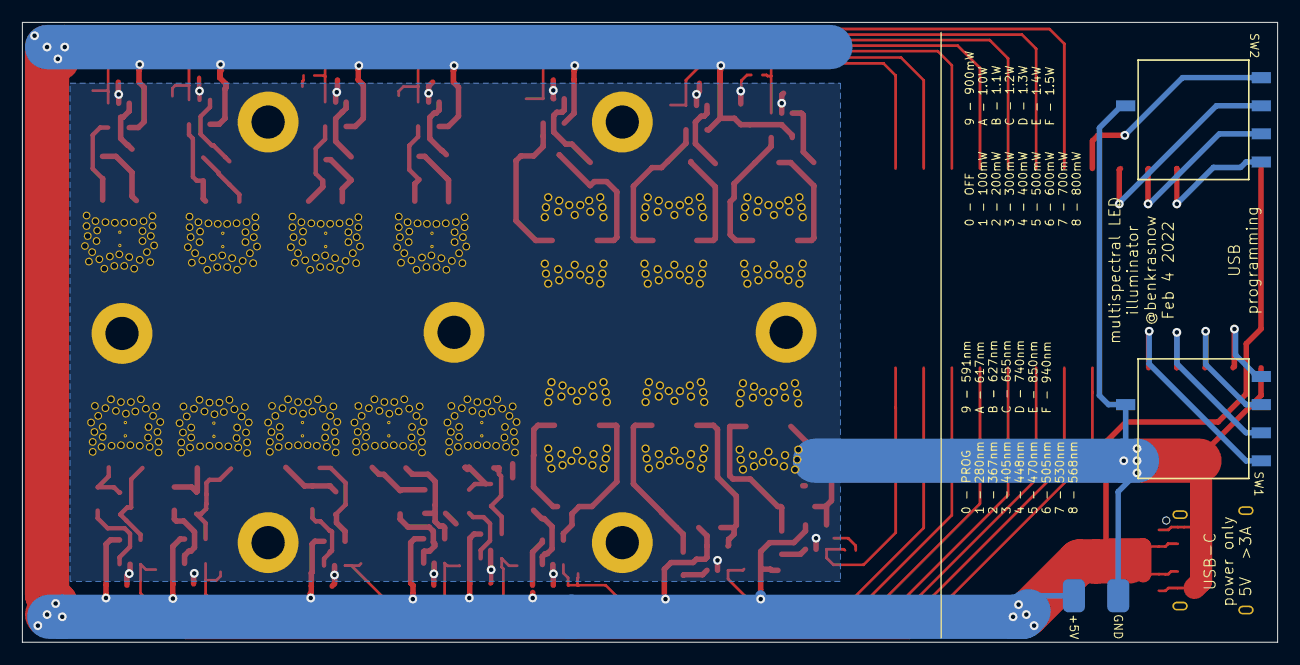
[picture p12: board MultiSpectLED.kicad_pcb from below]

Board: 2 copper layers, 113.4 x 56.0 mm, 117 parts (3 on the bottom side), 70 nets.

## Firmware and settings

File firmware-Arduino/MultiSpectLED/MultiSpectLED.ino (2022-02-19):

#include <SoftPWM.h>   //The library normally uses a 60Hz update rate which is defined in Arduino/hardware/teensy/avr/libraries/SoftPWM/SoftPWM.cpp


#define TWOPI 6.2832
#define PIOVERTWO 1.5708

#define PIN_LED_940 13
#define PIN_LED_850 14
#define PIN_LED_740 15
#define PIN_LED_655 16
#define PIN_LED_627 17
#define PIN_LED_617 18
#define PIN_LED_591 19
#define PIN_LED_568 5
#define PIN_LED_530 6
#define PIN_LED_505 7
#define PIN_LED_470 8
#define PIN_LED_448 9
#define PIN_LED_405 10
#define PIN_LED_367 11
#define PIN_LED_280 12


#define PIN_SEL1 0
#define PIN_SEL2 1
#define PIN_SEL4 2
#define PIN_SEL8 3

#define PIN_BRIGHT1 20
#define PIN_BRIGHT2 21
#define PIN_BRIGHT4 22
#define PIN_BRIGHT8 23

uint8_t led_array_pwm[15];
uint8_t led_array_pins[15] = {PIN_LED_280, PIN_LED_367, PIN_LED_405, PIN_LED_448, PIN_LED_470, PIN_LED_505, PIN_LED_530, PIN_LED_568, PIN_LED_591, PIN_LED_617, PIN_LED_627, PIN_LED_655, PIN_LED_740, PIN_LED_850, PIN_LED_940};
float cur_phase = 0;

void setup() {
  Serial.begin(9600);
  
   SoftPWMBegin();

   pinMode(PIN_SEL1, INPUT_PULLUP);
   pinMode(PIN_SEL2, INPUT_PULLUP);
   pinMode(PIN_SEL4, INPUT_PULLUP);
   pinMode(PIN_SEL8, INPUT_PULLUP);
   pinMode(PIN_BRIGHT1, INPUT_PULLUP);
   pinMode(PIN_BRIGHT2, INPUT_PULLUP);
   pinMode(PIN_BRIGHT4, INPUT_PULLUP);
   pinMode(PIN_BRIGHT8, INPUT_PULLUP);

   clear_all_leds();
}

void loop() {
  uint8_t cur_brightness = map(ReadLEDBrightness(),0,15,10,255);
  uint8_t cur_selection = ReadLEDSelection();
  
  clear_all_leds();
  
  cur_phase = (cur_phase > 7) ? -10 : cur_phase+0.08;
  
  if(cur_selection == 0)
  {
    for(int i = 0; i<15;i++)
      {
        led_array_pwm[i] = 255 * sine_pulse(cur_phase + i);      
      }
  }
  
  if(cur_selection > 0 && cur_selection < 16)
    {
      led_array_pwm[cur_selection-1] = cur_brightness;
    }
  update_leds();
  delay(16);
}




float sine_pulse(float input)  {
  if(input < 0)
    {
      return 0;
    }
  else if(input > TWOPI)
  {
    return 0;
  }
  else
  {
    return (1+sin(input-PIOVERTWO))/2;
  }
}

void update_leds(void)  {
  for(int i = 0; i<15;i++)
   {
    SoftPWMSet(led_array_pins[i], led_array_pwm[i]);
   }
}


void clear_all_leds(void)  {
  for(int i = 0; i<15;i++)
    {
      led_array_pwm[i] = 0;
    }
}


uint8_t ReadLEDSelection(void)  {
  uint8_t result = 0;
  result += !digitalRead(PIN_SEL1)<<0;
  result += !digitalRead(PIN_SEL2)<<1;
  result += !digitalRead(PIN_SEL4)<<2;
  result += !digitalRead(PIN_SEL8)<<3;
  return result; 
}


uint8_t ReadLEDBrightness(void)  {
  uint8_t result = 0;
  result += !digitalRead(PIN_BRIGHT1)<<0;
  result += !digitalRead(PIN_BRIGHT2)<<1;
  result += !digitalRead(PIN_BRIGHT4)<<2;
  result += !digitalRead(PIN_BRIGHT8)<<3;
  return result; 
}

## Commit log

2022-02-19 Added photos, pcb, and firmware
    [CUI_DEVICES_PJ-036AH-SMT-TR.step, FR02KR16P.stp, Luminus XBT-3535_DF_102620.STEP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]
2022-02-20 Added pulldown resistors on each PAM2804 enable line
    [MultiSpectLED.kicad_pcb, MultiSpectLED.sch]

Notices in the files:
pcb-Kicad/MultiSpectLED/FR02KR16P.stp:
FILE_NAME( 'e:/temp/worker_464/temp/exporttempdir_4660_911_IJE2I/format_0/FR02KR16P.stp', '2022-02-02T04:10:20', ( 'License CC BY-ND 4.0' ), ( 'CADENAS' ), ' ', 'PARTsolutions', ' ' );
